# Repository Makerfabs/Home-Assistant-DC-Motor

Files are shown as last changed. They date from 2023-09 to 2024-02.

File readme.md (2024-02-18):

# Makerfabs Home Assistant DC Motor

```c++
/*
Version:        V1.1
Author:            Vincent
Create Date:    2023/9/13
Note:
    2023/10/23  V1.1: Add Endstop Usage
*/
```

main

# Makerfabs

[Makerfabs home page](https://www.makerfabs.com/)

[Makerfabs Wiki](https://wiki.makerfabs.com/)

## Intruduce

[Product Link](https://www.makerfabs.com/dc-motor-for-home-assistant-ga36y-555-html.html)

[Wiki Link](https://wiki.makerfabs.com/How_to_use_DC_Motor_for_Home_Assistant_GA36Y555.html)   

## Features

- Controller: ESP32

# Equipping Items
Install the Home assistant firmware of Raspberry PI, or other platforms, and ensure that you can log in to the management page.

And install the ESPHome in the Add-on.

Version of this document:
 
``` c
ESPHome
Current version: 2023.5.1

```

Equipment Setup

1. Open the HA management page and go to the ESPHome page.

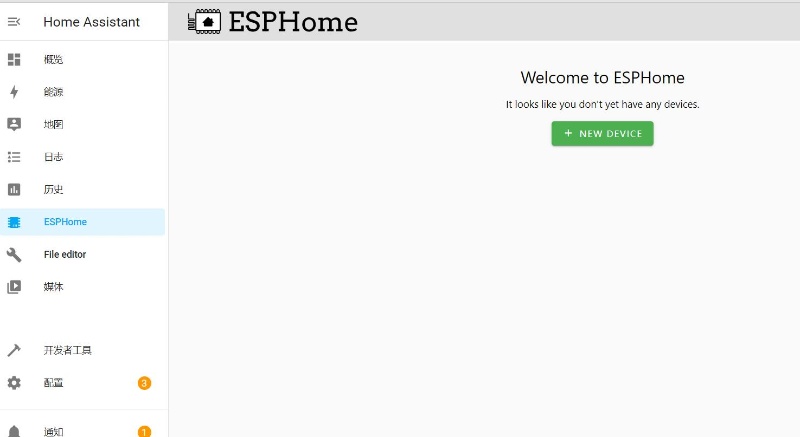
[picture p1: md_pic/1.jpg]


2. Select NEW DEVICE.
3. Select Continue.
4. Set a name, such as HA-Motor.

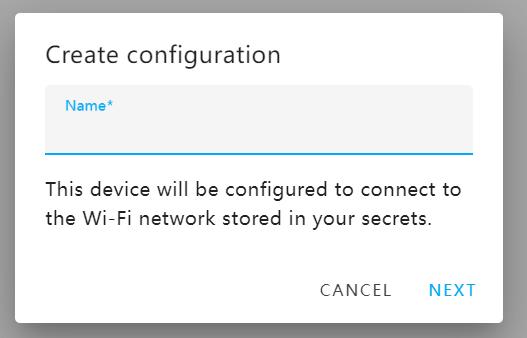
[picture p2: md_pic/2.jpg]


5. Select ESP32.

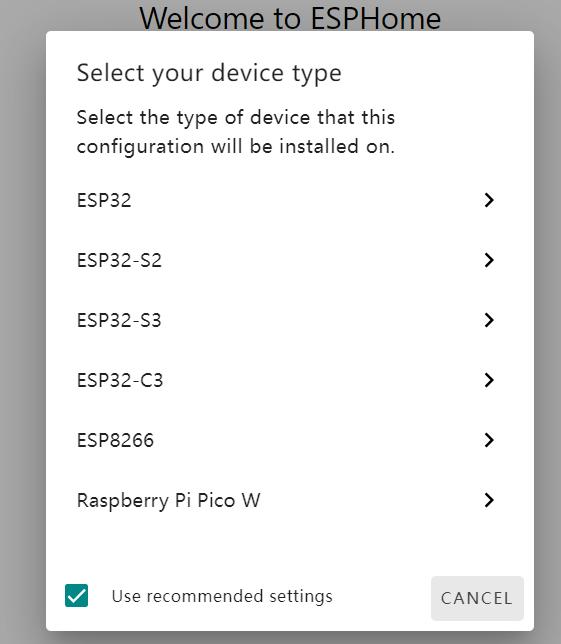
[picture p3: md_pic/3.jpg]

 
6. Select SKIP, you will return to the ESPHome page, you will see the device you just created.
7. Select EDIT to enter the yaml file editing page

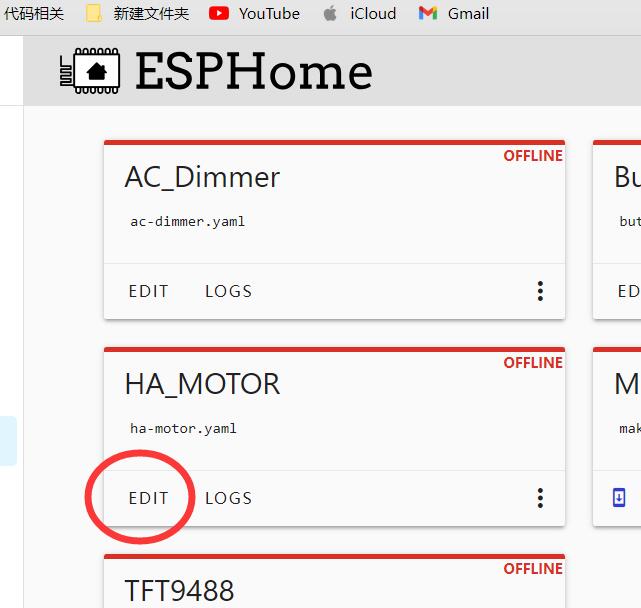
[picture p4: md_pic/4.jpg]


8. Copy the code ha-motor.yaml provided by Makerfabs to the end of the file.

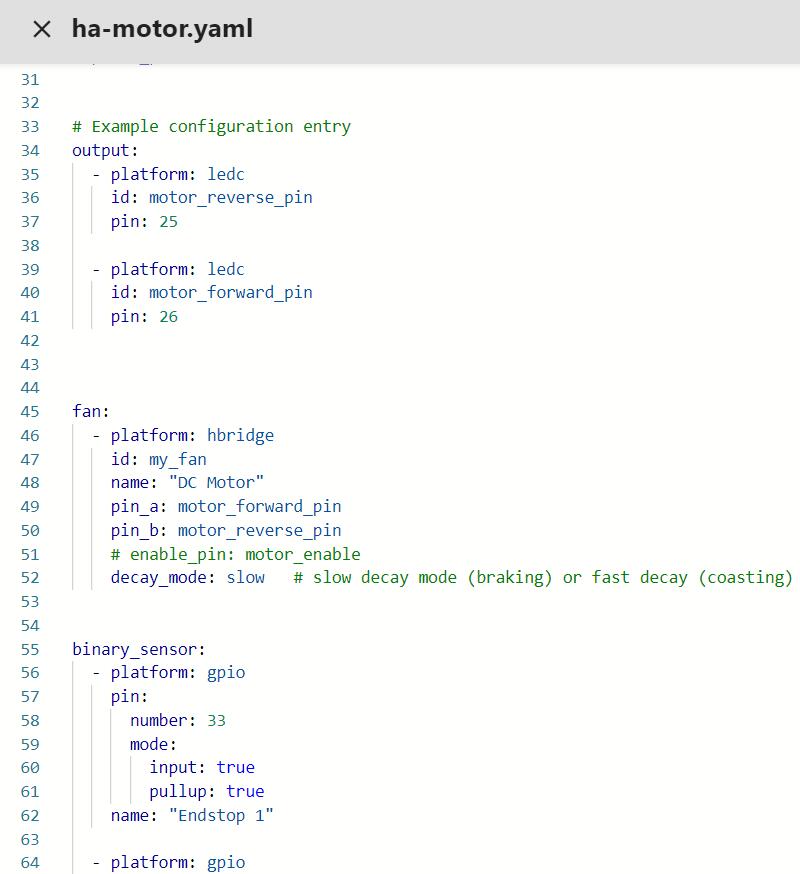
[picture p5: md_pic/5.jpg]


9. Select SAVE, and select Install.
10. Select Manual Download, select Modern format, the console page will be displayed, please wait patiently for compilation.

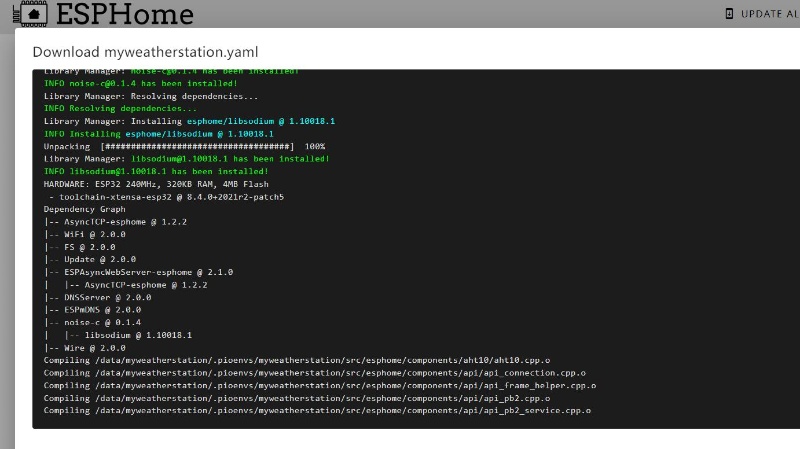
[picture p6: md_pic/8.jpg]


11. After the bin file is downloaded, exit.
12. Open https://web.esphome.io/?dashboard_install, go to the download page

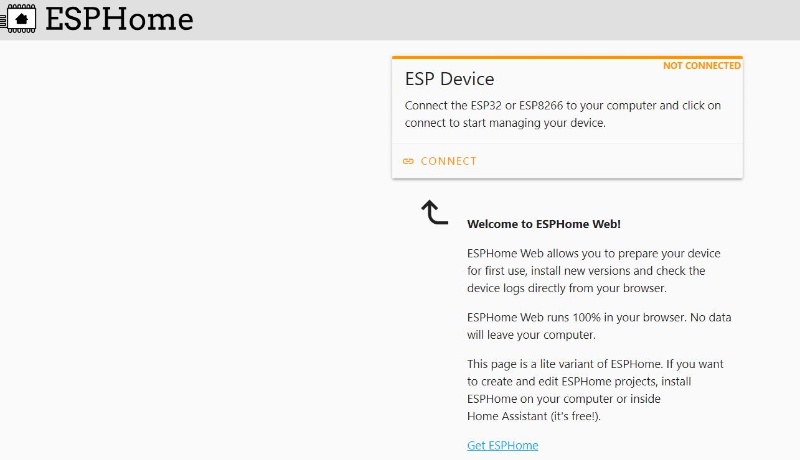
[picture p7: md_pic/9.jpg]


13. Select CONNECT. In the displayed page, select COM port.

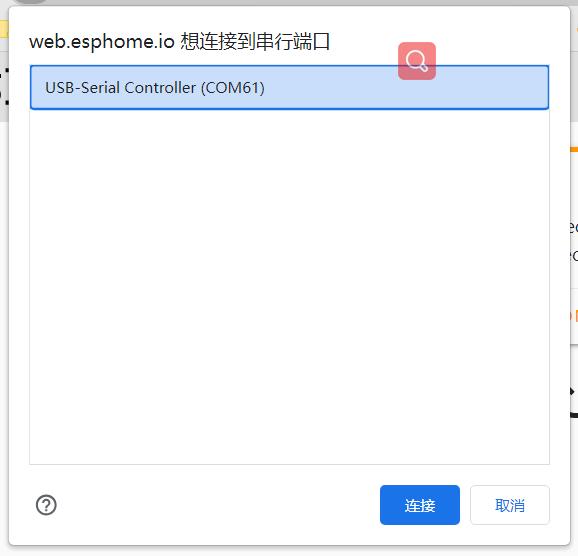
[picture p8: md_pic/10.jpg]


14. After the connection is successful, click INSTALL

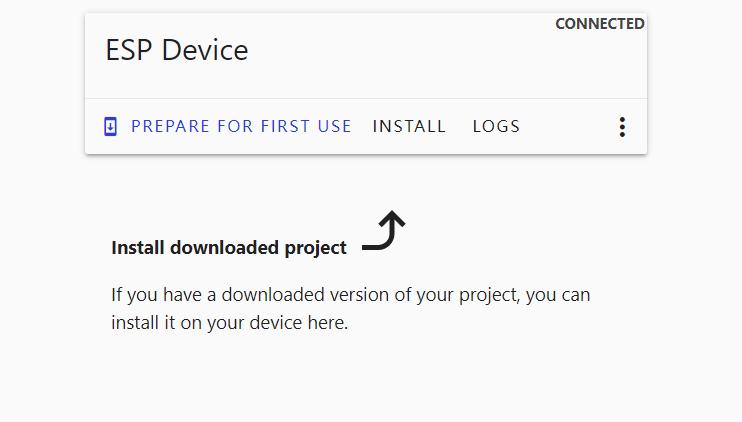
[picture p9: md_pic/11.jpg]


15. Select the bin file you just downloaded on the pop-up page. Click Install and wait for the installation to complete. If the connection is not successful, hold down the Flash key, then press the Reset key, and then click Download again.
16. download success, click, LOGS pop-up terminal interface, find IP information

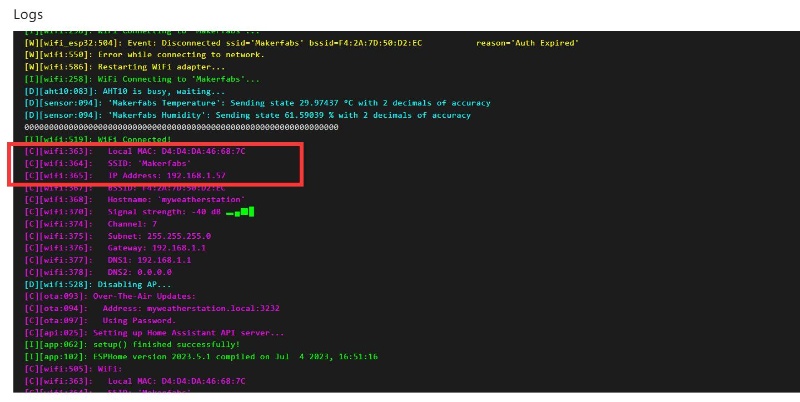
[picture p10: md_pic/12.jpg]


17. Go back to the ESPHome page, select EDIT for your device, and go to the YAML edit page.
18. Copy API: encryption key: the back of the content, such as “43 a0nyfb9py7aalga282lgikxkt5i7zhcmu8dhmjnea=”
19. Return to the HA page, select Configuration, and select devices and services
20. If HA automatically identifies the local device, click Configure to add the device automatically. If no, continue to add the device. This is related to the configuration of the HA router.
21. Click on the bottom right corner to add integration, search for ESPHome, and select
22. Enter the IP address you just obtained on the pop-up page, such as 192.168.1.57, and then submit.
23. Enter the key.

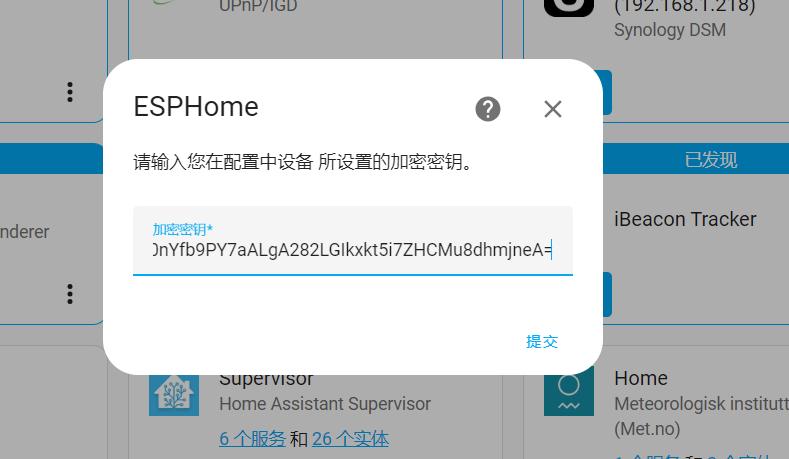
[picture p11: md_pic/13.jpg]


24. The device has been added successfully

# HA UI Setup

Normally, HA recognizes this automatically, but if the home page has been manually modified, HA will never add any device display again.

1. Go to the HA home page, click the three dots in the upper right corner, select Edit dashboard

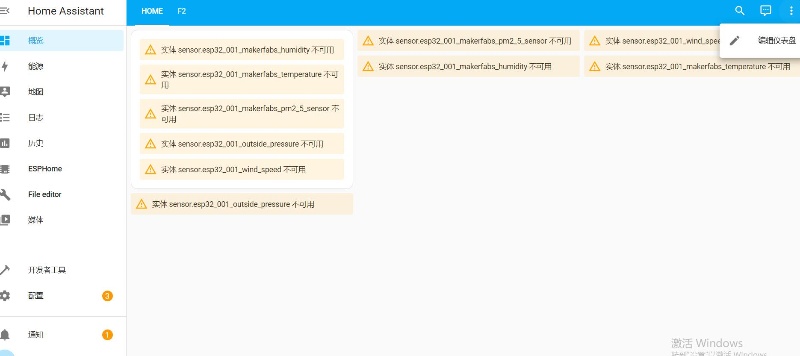
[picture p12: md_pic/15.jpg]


2. The color of the interface changes, select the add card in the lower right corner.
3. In the physical page there are many cards to choose from, here select a dial, click

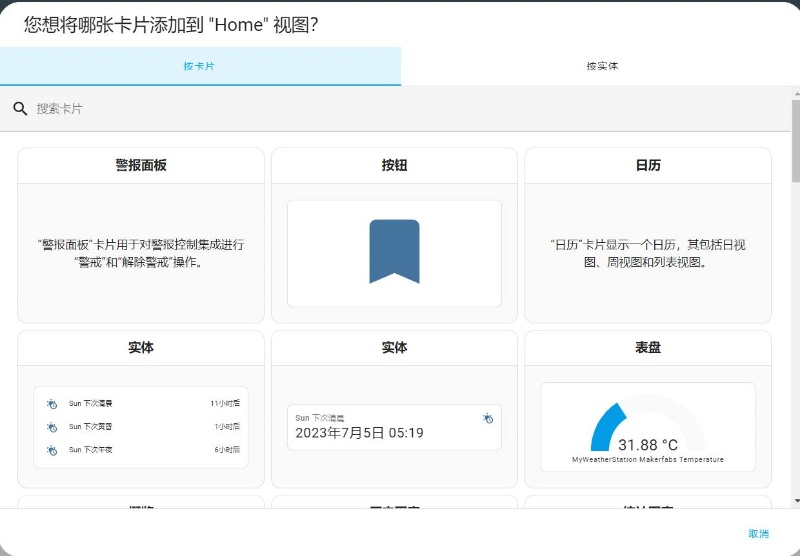
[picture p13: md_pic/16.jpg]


4. In the dial card configuration page, select the entity, find the relevant content of LAN_test

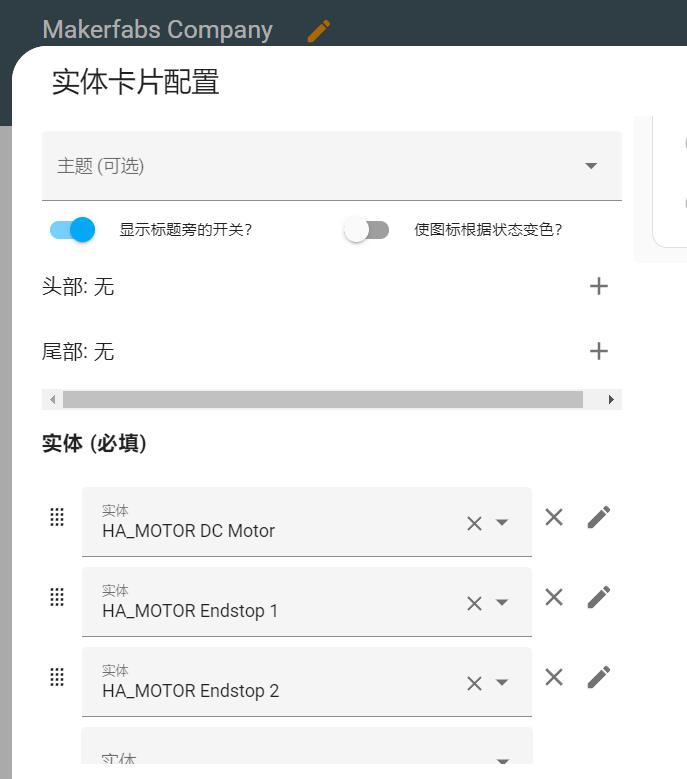
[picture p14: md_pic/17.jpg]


5. Save.
6. The way to add cards is the same as the use of HA, you can arrange the page by yourself.
7. Click Finish to exit editing
The reference interface is as follows:

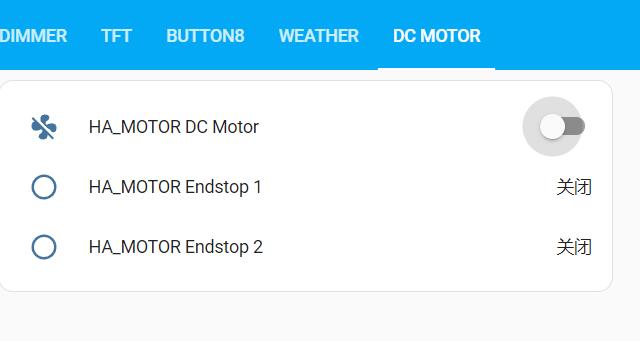
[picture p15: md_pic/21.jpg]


# HA Automation

Two new Endstop pads are added to connect the external Endstop.

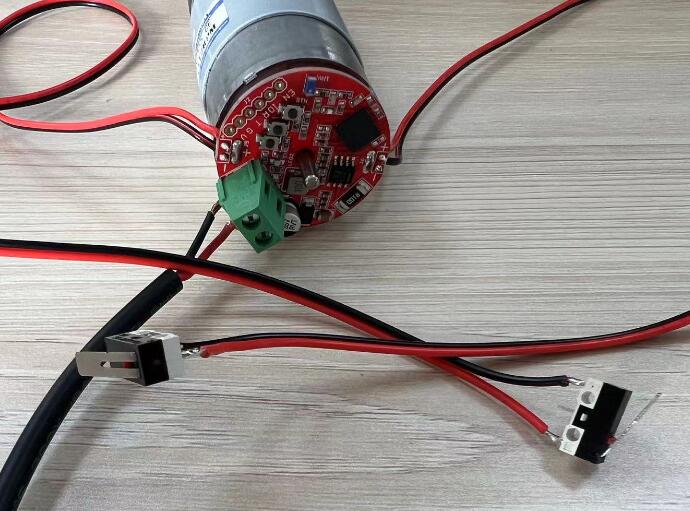
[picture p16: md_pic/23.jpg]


For example, if you want Endstop 1 to be triggered, turn off the motor, you can see the following Settings.
On the configuration page, select Automation.
Select Create Automation and set trigger conditions and motors.

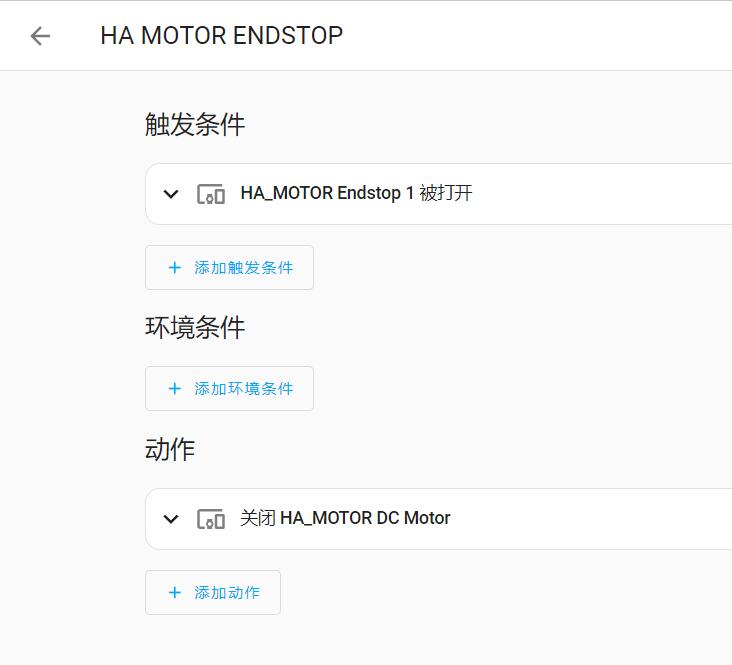
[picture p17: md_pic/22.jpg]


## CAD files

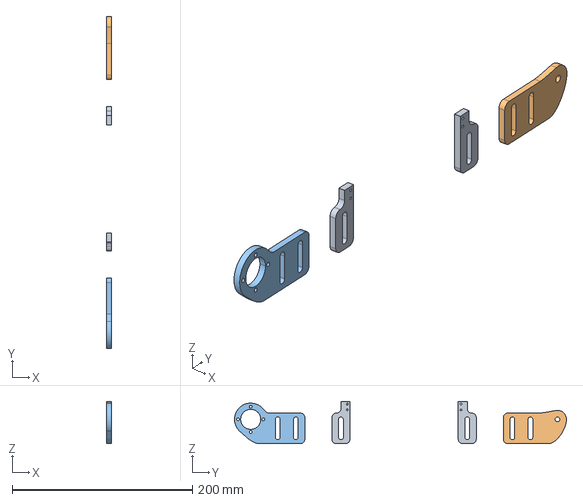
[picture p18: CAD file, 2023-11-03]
3d_file/HA_MOTOR.stp
5.00 x 368.0 x 47.0 mm

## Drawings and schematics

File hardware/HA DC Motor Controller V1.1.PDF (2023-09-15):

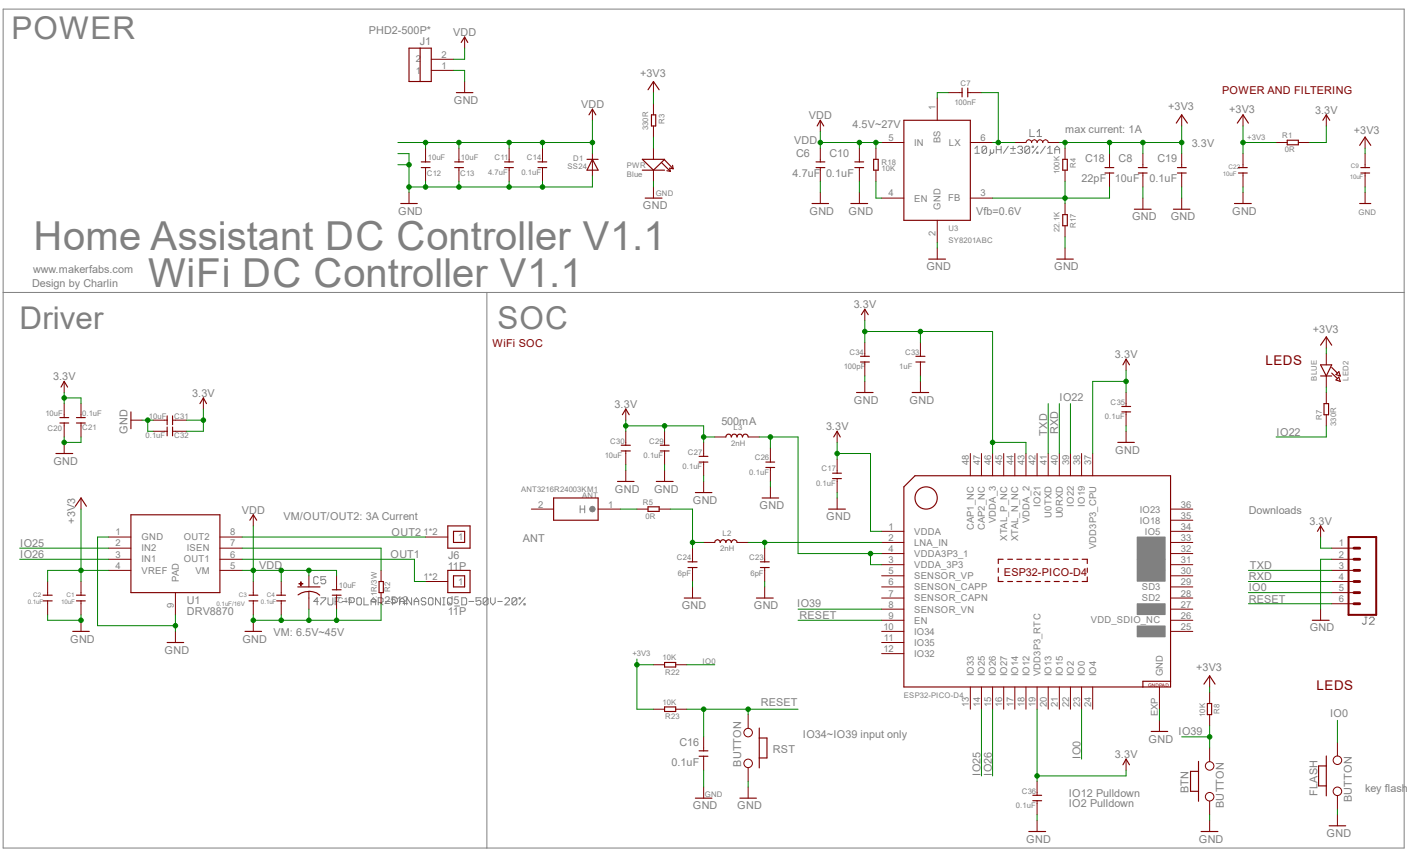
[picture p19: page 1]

Home Assistant DC Controller V1.1
Downloads WiFi DC Controller V1.1

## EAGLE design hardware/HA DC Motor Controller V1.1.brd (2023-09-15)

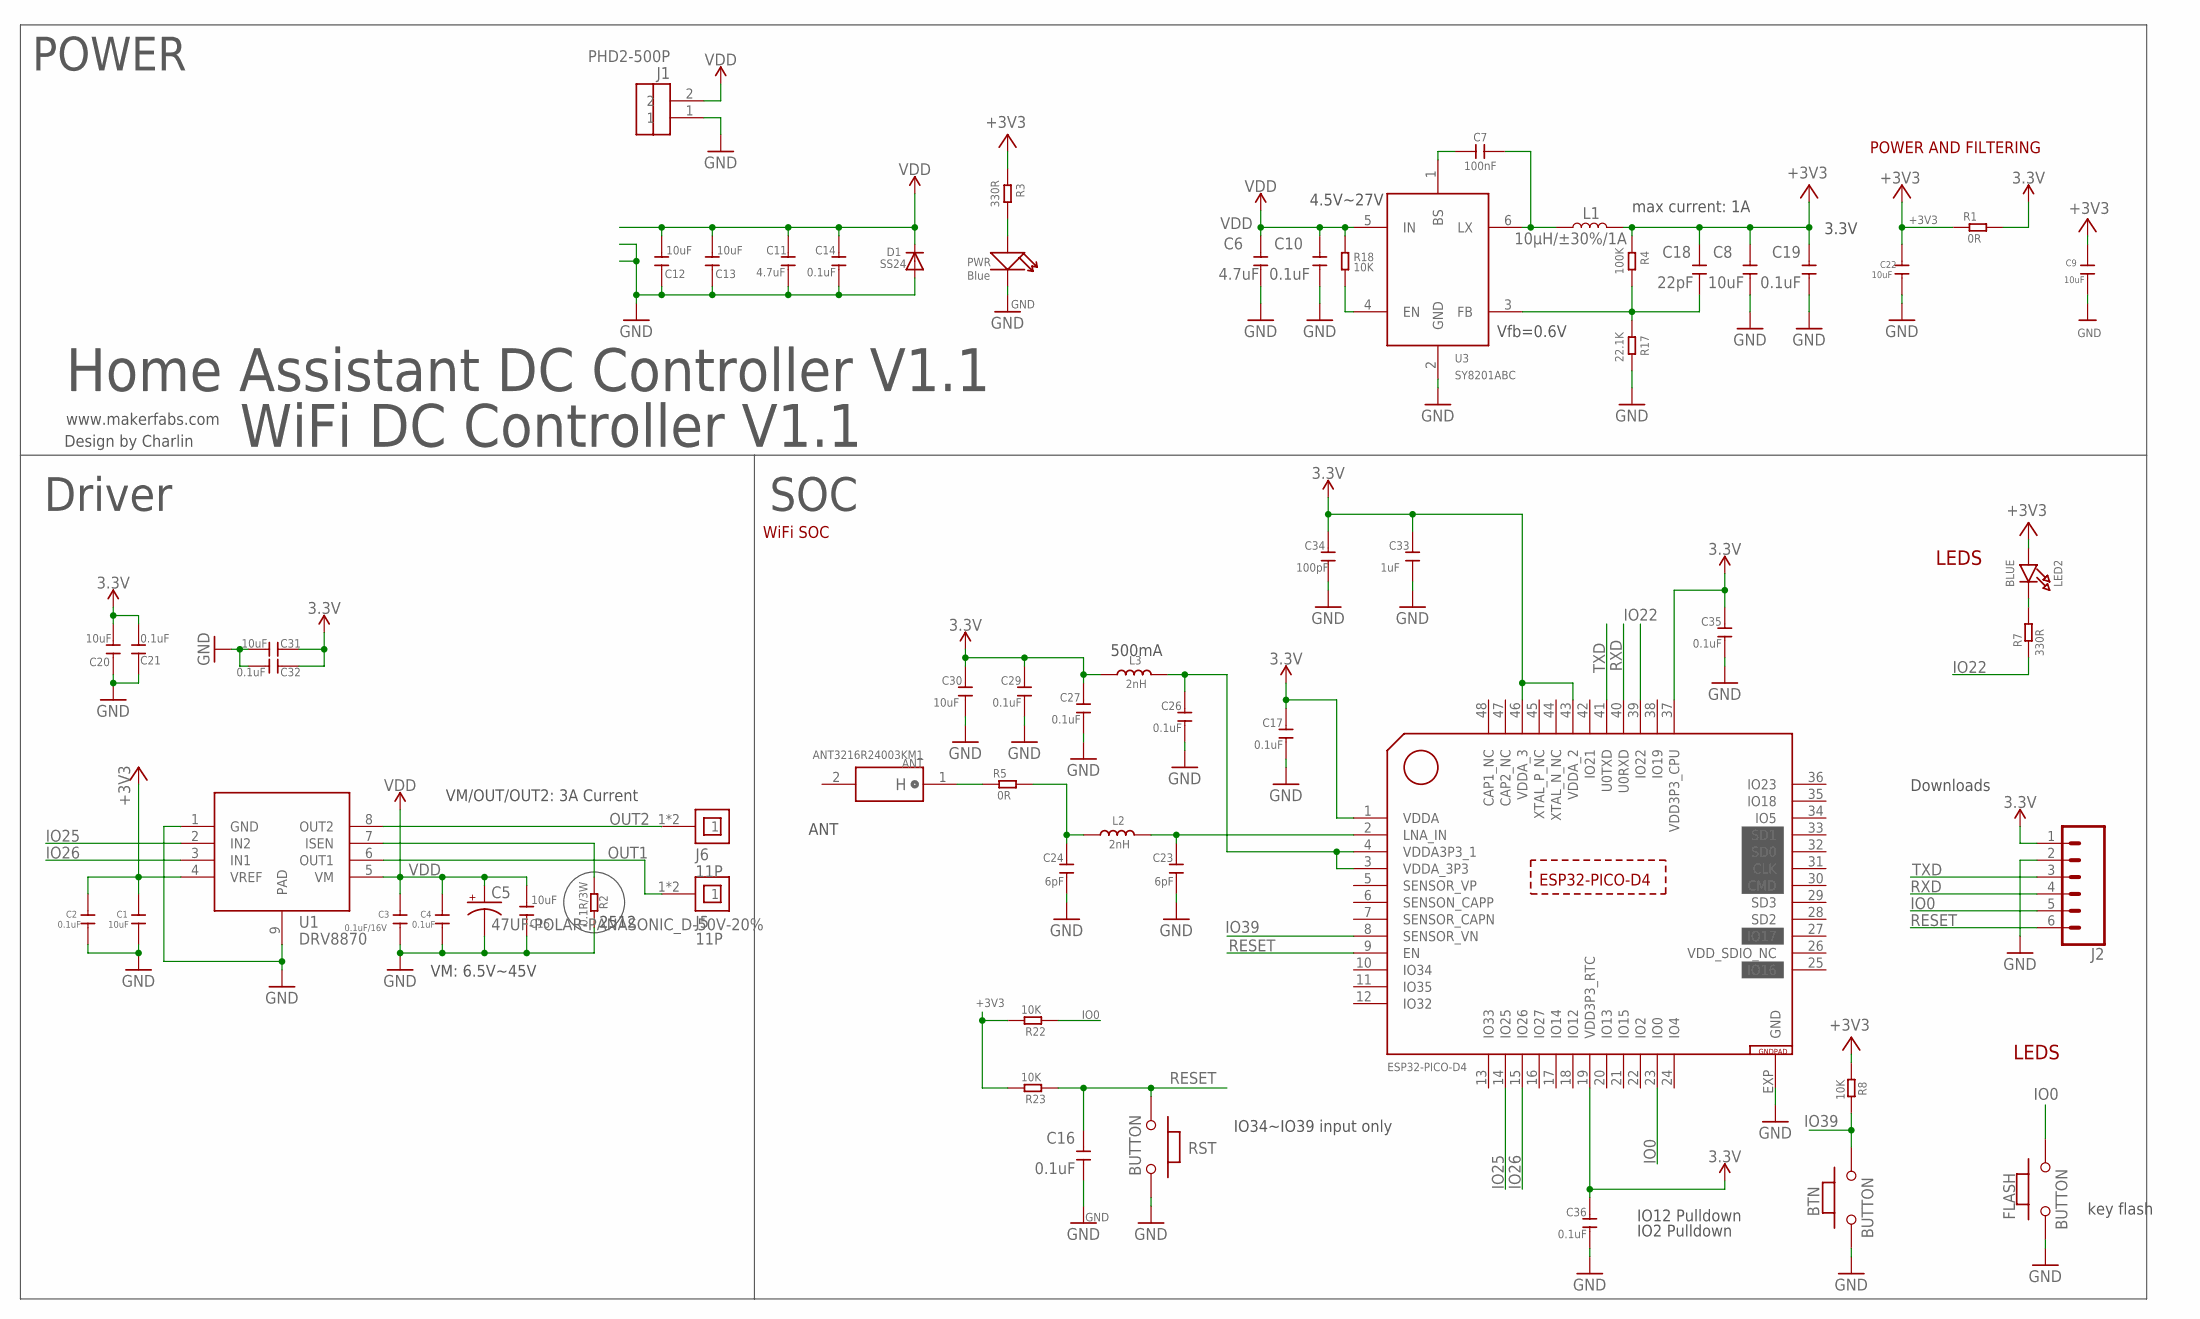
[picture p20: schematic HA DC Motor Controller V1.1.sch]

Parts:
ANT: ANT3216R24003KM1; ANT-1206
BTN: BUTTON; 157SW
C1, C8, C9, C22, C30: 10uF; 0603
C2, C4, C10, C14, C16, C17, C19, C26, C27, C29, C35, C36: 0.1uF; 0603
C3: 0.1uF/16V; 0603
C5: 47UF-POLAR-PANASONIC_D-50V-20%; PANASONIC_D
C6, C11: 4.7uF; 0603
C7: 100nF; 0603
C12, C13, C15: 10uF; DISCRETE_C1206
C18: 22pF; 0603
C20, C31: 10uF; DISCRETE_C0603
C21, C32: 0.1uF; DISCRETE_C0603
C23, C24: 6pF; 0603
C33: 1uF; 0603
C34: 100pF; 0603
D1: SS24; SMADIODE
FLASH: BUTTON; 157SW
J1: PHD2-500P; OPL_EAGLE_LIBRARY_2P-5.0
J2: CONN_06SILK_FEMALE_PTH; 1X06
J5, J6: 11P; 1*1P-4*1MM
L1: 10µH/±30%/1A; CR54
L2, L3: 2nH; DISCRETE_L0603
LED2: BLUE; CHIPLED_0805_NOOUTLINE
PWR: Blue; LED-0603
R1, R5: 0R; R0603
R2: 0.1R/3W; DISCRETE_R2512
R3, R7: 330R; R0603
R4: 100K; R0603
R8, R18, R22, R23: 10K; R0603
R17: 22.1K; R0603
RST: BUTTON; 157SW
U1: DRV8870; SOP-8-EP
U3: SY8201ABC; SOT-23-6
U$2: ESP32-PICO-D4; QFN48

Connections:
3.3V: C17.2, C20.2, C21.2, C27.2, C29.2, C30.2, C31.1, C32.1, C33.2, C34.2, C35.2, C36.2, J2.1, L3.1, R1.2, U$2.1 (VDDA), U$2.19 (VDD3P3_RTC), U$2.37 (VDD3P3_CPU), U$2.43 (VDDA_2), U$2.46 (VDDA_3)
+3V3: C1.1, C2.1, C8.2, C9.1, C18.2, C19.2, C22.1, L1.P$2 (2), LED2.A, R1.1, R3.1, R4.1, R8.1, R22.2, R23.2, U1.4 (VREF)
GND: BTN.1, C1.2, C2.2, C3.2, C4.2, C5.-, C6.1, C8.1, C9.2, C10.1, C11.1, C12.1, C13.1, C14.1, C15.1, C16.1, C17.1, C19.1, C20.1, C21.1, C22.2, C23.1, C24.1, C26.1, C27.1, C29.1, C30.1, C31.2, C32.2, C33.1, C34.1, C35.1, C36.1, D1.A, FLASH.1, J1.1, J2.2, PWR.-, R2.1, R17.2, RST.1, U1.1 (GND), U1.9 (PAD), U3.2 (GND), U$2.EXP (GND)
IO0: FLASH.2, J2.5, R22.1, U$2.23 (IO0)
IO22: R7.1, U$2.39 (IO22)
IO25: U1.2 (IN2), U$2.14 (IO25)
IO26: U1.3 (IN1), U$2.15 (IO26)
IO39: BTN.2, R8.2, U$2.8 (SENSOR_VN)
unnamed: PWR.+, R3.2
unnamed: C7.2, L1.P$1 (1), U3.6 (LX)
unnamed: C7.1, U3.1 (BS)
unnamed: R2.2, U1.7 (ISEN)
unnamed: C18.1, R4.2, R17.1, U3.3 (FB)
unnamed: R18.2, U3.4 (EN)
unnamed: C26.2, L3.2, U$2.3 (VDDA_3P3), U$2.4 (VDDA3P3_1)
unnamed: C23.2, L2.2, U$2.2 (LNA_IN)
unnamed: C24.2, L2.1, R5.2
unnamed: ANT.1, R5.1
unnamed: LED2.C, R7.2
OUT1: J5.1, J5.1@1, U1.6 (OUT1)
OUT2: J6.1, J6.1@1, U1.8 (OUT2)
RESET: C16.2, J2.6, R23.1, RST.2, U$2.9 (EN)
RXD: J2.4, U$2.40 (U0RXD)
TXD: J2.3, U$2.41 (U0TXD)
VDD: C3.1, C4.1, C5.+, C6.2, C10.2, C11.2, C12.2, C13.2, C14.2, C15.2, D1.C, J1.2, R18.1, U1.5 (VM), U3.5 (IN)
VDD_SDIO_NC: U$2.26 (VDD_SDIO_NC)

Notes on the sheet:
www.makerfabs.com
Design by Charlin
LEDS
POWER AND FILTERING
WiFi SOC
key flash
Home Assistant DC Controller V1.1
IO34~IO39 input only
POWER
SOC
VM/OUT/OUT2: 3A Current
VM: 6.5V~45V
2512
Vfb=0.6V
3.3V
4.5V~27V
max current: 1A
IO12 Pulldown
IO2 Pulldown
500mA
ANT
Downloads
WiFi DC Controller V1.1
Driver

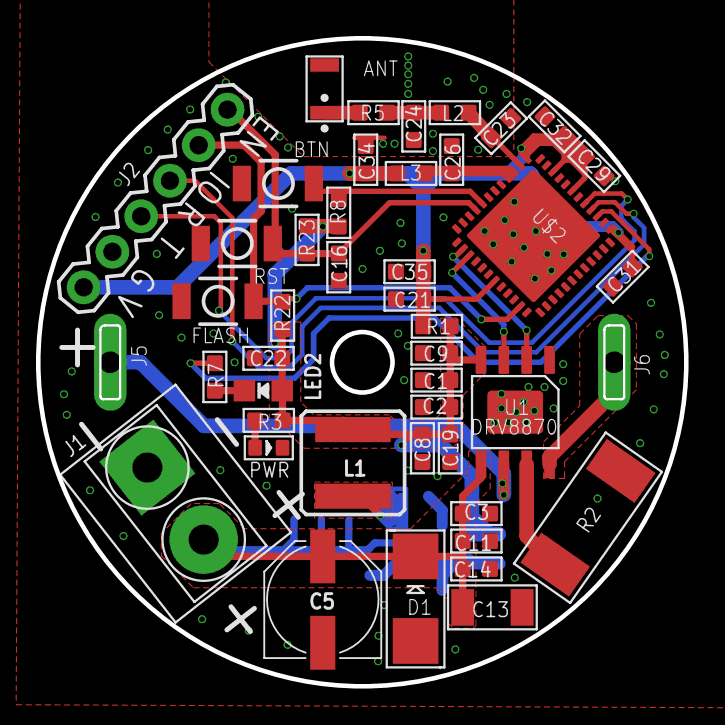
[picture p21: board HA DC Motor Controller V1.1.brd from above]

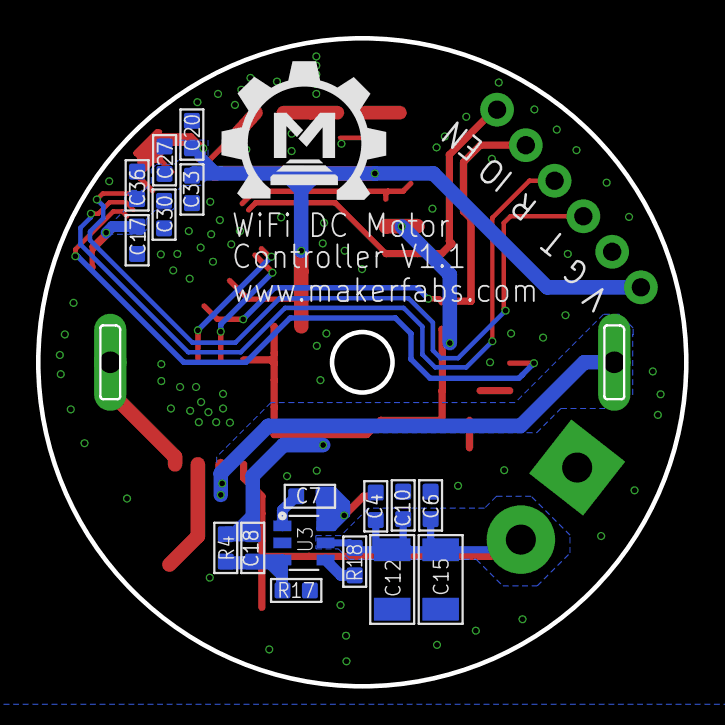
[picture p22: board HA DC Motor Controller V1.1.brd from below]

Board: 2 copper layers, 36.0 x 36.0 mm, 63 parts (18 on the bottom side), 25 nets.

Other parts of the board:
U$1: MAKERFABS_0.3

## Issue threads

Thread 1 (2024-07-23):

Direction change not wokring through automation

whitexichigo, 2024-07-23:
I simple created a easy automation which will change the motor direction and turn it then on, but the motor turns on but the direction change does not work, the order is not important i tried.

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

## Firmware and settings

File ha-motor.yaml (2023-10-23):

# Example configuration entry
output:
  - platform: ledc
    id: motor_reverse_pin
    pin: 25

  - platform: ledc
    id: motor_forward_pin
    pin: 26



fan:
  - platform: hbridge
    id: my_fan
    name: "DC Motor"
    pin_a: motor_forward_pin
    pin_b: motor_reverse_pin
    # enable_pin: motor_enable
    decay_mode: slow   # slow decay mode (braking) or fast decay (coasting)


binary_sensor:
  - platform: gpio
    pin: 33
    name: "Endstop 1"
    filters:
      - invert:

  - platform: gpio
    pin: 32
    name: "Endstop 2"
    filters:
      - invert:

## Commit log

2023-09-15 Add hardware
    [HA DC Motor Controller V1.1.brd, HA DC Motor Controller V1.1.sch]
2023-10-23 V1.1 Add endstop
    [ha-motor.yaml]

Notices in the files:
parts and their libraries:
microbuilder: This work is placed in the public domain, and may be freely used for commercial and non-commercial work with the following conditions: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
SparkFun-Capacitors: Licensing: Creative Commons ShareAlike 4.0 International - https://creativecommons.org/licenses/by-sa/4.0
